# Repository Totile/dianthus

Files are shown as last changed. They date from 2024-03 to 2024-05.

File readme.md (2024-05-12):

# Dianthus

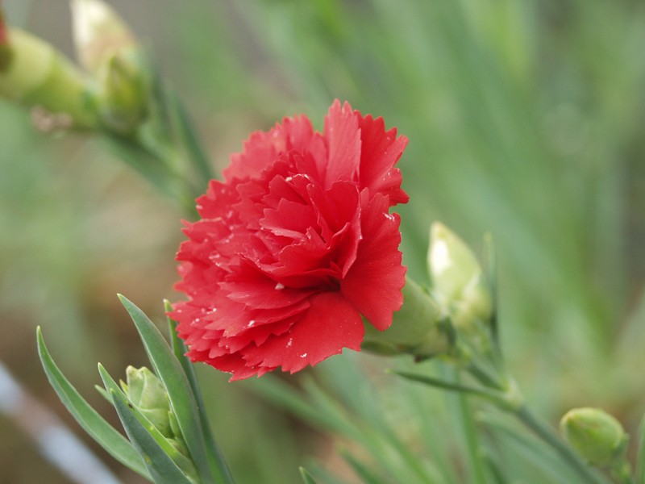
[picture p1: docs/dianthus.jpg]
Dianthus


*In the world of GUI, less mouse pointers, more fat fingers buttons.* 

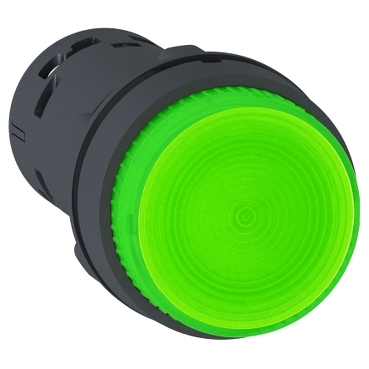
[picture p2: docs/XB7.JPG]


A button box to interface with web-based GUI, when you want to just push on buttons to do repetitive tasks. This replaces the need for the small buttons of a keyboard, or *worse*, a MOUSE.

* Hardware Supported: This box is based on the XB7 industrial button from Schneider electrics. And a promicro development board.
* Hardware Availability: 

## Installation guide

## Fabrication guide

All related documents can be found on the `livrables` folder (Procurement list, PCB production file, STL, ...)

### PCB Fabrication

### Schneider customisation button

### 3D printing files

The source files can be found on [Onshape project](https://cad.onshape.com/documents/cb52971ac28a8f36a2bdde5f/w/7d97d8c1100cd4f538ea172c/e/2ed6b61c8d6aeb3da16c9e53).

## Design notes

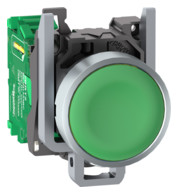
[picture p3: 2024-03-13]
docs/img/bigButton.jpg

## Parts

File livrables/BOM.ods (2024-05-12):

Nom | Quantité | Lien | Commentaire
Connecteur M12 vers câble | 1 | https://www.reichelt.de/fr/en/built-in-coupling-m12-5-pin-a-coded-ip67-black-lut-1220-05-100-p347082.html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
Alimentation 24V | 1 | https://www.automation24.fr/bloc-dalimentation-electrique-ifm-electronic-e80120
Câble Micro USB to USB-A | 1 | https://www.reichelt.de/fr/en/usb-a-connector-to-usb-micro-b-connector-green-2-m-shvp-bs1450015-p241114.html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
Connecteur USB A vers USB B | 1 | https://fr.rs-online.com/web/p/connecteurs-usb/8621573
Câble USB-B vers A | 1 | Voir ./fab
PCB | 1
Boîte | 1
Câble JST SH free on one side | 1 | https://www.mouser.de/ProductDetail/SparkFun/PRT-14426?qs=wd5RIQLrsJiogglVGK6o1w%3D%3D&vip=1&gad_source=1 | https://www.reichelt.de/fr/en/arduino-grove-universal-cable-4-pin-30cm-buckled-5er-bag--grv-cable4pin30f-p191162.html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
Bouton poussoir rétroéclairé | 5 | https://www.rexel.fr/frx/Cat%C3%A9gorie/Produits-Industriels/Commande-et-signalisation/Bouton-poussoir-et-tournant/Harmony-bouton-poussoir-lumineux---D%3D22--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 | XB7NW33B1
Boite ABPH 1600/1680 x 100 | 1 |  | https://www.bopla.de/fr/technique-de-boitiers/bos-ecoline/profiles-de-boitier-divises-horizontalement-2
Support mural pour ABPH | 1 | https://www.bopla.de/fr/technique-de-boitiers/alubos/accessoires-6
Fixation VESA | 1 | https://www.bopla.de/fr/technique-de-boitiers/presse-etoupes-accessoires-universels/clips-et-supports

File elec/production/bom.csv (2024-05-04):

Designator | Footprint | Quantity | Value | LCSC Part #
C1 | 0402 | 1 | 0.1uF
C2 | 1206 | 1 | 10uF
J1 | DB301V-3.5-2P-GN-S | 1 | Screw terminal
J10, J11, J12, J2, J3, J4, J5, J6, J7, J8, J9 | JST_SH_BM04B-SRSS-TB_1x04-1MP_P1.00mm_Vertical | 11 | BM04B-SRSS-TB
MCU1 | ProMicro | 1 | ATMEGA32UA_PROMICRO
Q1, Q10, Q2, Q3, Q4, Q5, Q6, Q7, Q8, Q9 | SOT-23 | 10 | 2N7002
R1, R11, R13, R15, R17, R19, R2, R21, R23, R25, R27, R3, R4, R5, R6, R9 | 0805 | 16 | 10k
R10, R12, R14, R16, R18, R20, R22, R24, R26, R28 | 0805 | 10 | 1k
R7, R8 | 0805 | 2 | 4.7k
SW1 | YTS-C015-X | 1 | YTSA010
TP1, TP2, TP3, TP4, TP5 | TestPoint_THTPad_D3.0mm_Drill1.5mm | 5 | TestPoint_Probe
U1 | DIP-28_W7.62mm | 1 | MCP23017_SP

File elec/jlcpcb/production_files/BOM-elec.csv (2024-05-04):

Comment | Designator | Footprint | LCSC
10uF | C2 | C_1206_3216Metric | C13585
BM04B-SRSS-TB | J10,J11,J12,J2,J3,J4,J5,J6,J7,J8,J9 | JST_SH_BM04B-SRSS-TB_1x04-1MP_P1.00mm_Vertical | C160390
10k | R1,R11,R13,R15,R17,R19,R2,R21,R23,R25,R27,R3,R4,R5,R6,R9 | R_0805_2012Metric | C17414
1k | R10,R12,R14,R16,R18,R20,R22,R24,R26,R28 | R_0805_2012Metric | C17513
4.7k | R7,R8 | R_0805_2012Metric | C17675
YTSA010 | SW1 | YTS-C015-X | C2910844
0.1uF | C1 | C_0402_1005Metric | C307331
Screw terminal | J1 | DB301V-3.5-2P-GN-S | C695629
2N7002 | Q1,Q10,Q2,Q3,Q4,Q5,Q6,Q7,Q8,Q9 | SOT-23 | C8545
MCP23017_SP | U1 | DIP-28_W7.62mm
TestPoint_Probe | TP3 | TestPoint_THTPad_D3.0mm_Drill1.5mm
TestPoint_Probe | TP1 | TestPoint_THTPad_D3.0mm_Drill1.5mm
TestPoint_Probe | TP5 | TestPoint_THTPad_D3.0mm_Drill1.5mm
TestPoint_Probe | TP2 | TestPoint_THTPad_D3.0mm_Drill1.5mm
ATMEGA32UA_PROMICRO | MCU1 | ProMicro
TestPoint_Probe | TP4 | TestPoint_THTPad_D3.0mm_Drill1.5mm

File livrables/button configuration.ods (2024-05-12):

Description | Modular Product ID | Customisation code | Configuration file | Customisation code with bevel | Ordering process
UD / BD Blanc | ZB4BZ102 / ZBVB1 / ZB4BW313 | ZB4-24054AEDC | harmonyxb4-0506-2103.se | ZB4-2405328OC | Complete product / Illuminated Push button / Chromium plated / Round / Built-in flush / flush / Spring return / White / Yes / NO / 24V / AC/DC / With plain lens / Screw-clamp terminal / Basic sub assemblies / mounting 22.5 mm
Mesurer orange | ZB4BZ102 / ZBVB1 / ZB4BW353 | ZB4-24055GUYV | harmonyxb4-0506-2102.se | XB4-24054A48Y
Plat vert | ZB4BZ102 / ZBVB1 / ZB4BW333 | ZB4-24054AEDC | harmonyxb4-0506-2109.se | XB4-24054A4MR
Courbe rouge | ZB4BZ102 / ZBVB1 / ZB4BW343 | ZB4-24055GV77 | harmonyxb4-0506-2113.se | XB4-24054A4Y4 | 703 | Trend / 5847 | Tilde operator
Valider blanc | ZB4BZ102 / ZBVB1 / ZB4BW313 | ZB4-24055GVDY | harmonyxb4-0506-2133.se | ZB4-24054A6GX | 422 | Affirmative / selection / 6334A
Enregistrer bleu | ZB4BZ102 / ZBVB1 / ZB4BW363 | ZB4-24055GVQZ | harmonyxb4-0506-2137.se | XB4-24054A6QL

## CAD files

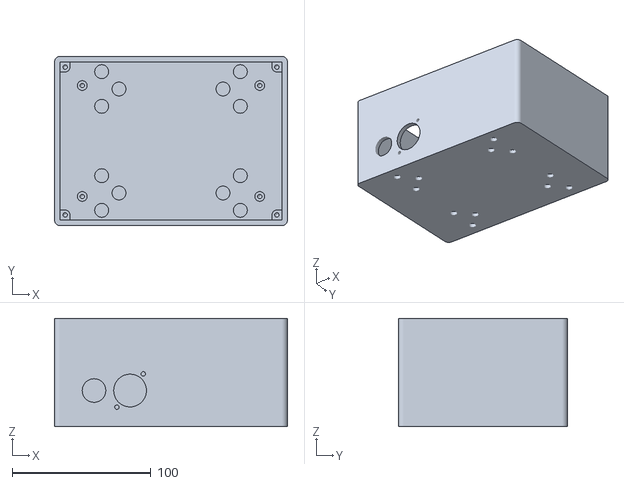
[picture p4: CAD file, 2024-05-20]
livrables/enclosure/box.stl
168.0 x 122.0 x 78.0

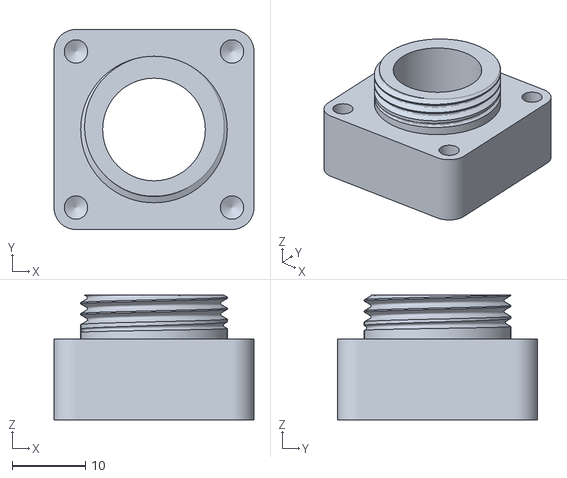
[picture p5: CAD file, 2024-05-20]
livrables/enclosure/rotary encoder housing.stl
27.3 x 27.3 x 17.0

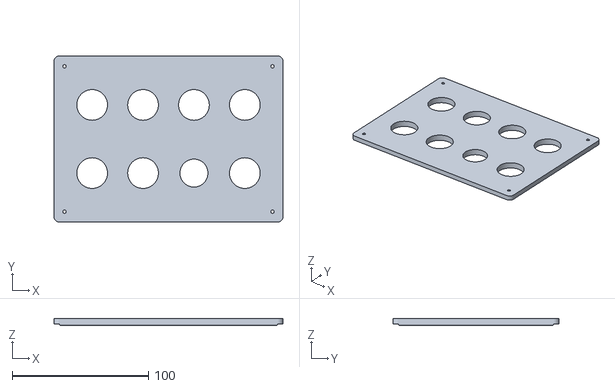
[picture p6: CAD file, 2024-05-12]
livrables/enclosure/cap 8 holes.stl
168.0 x 122.0 x 5.00

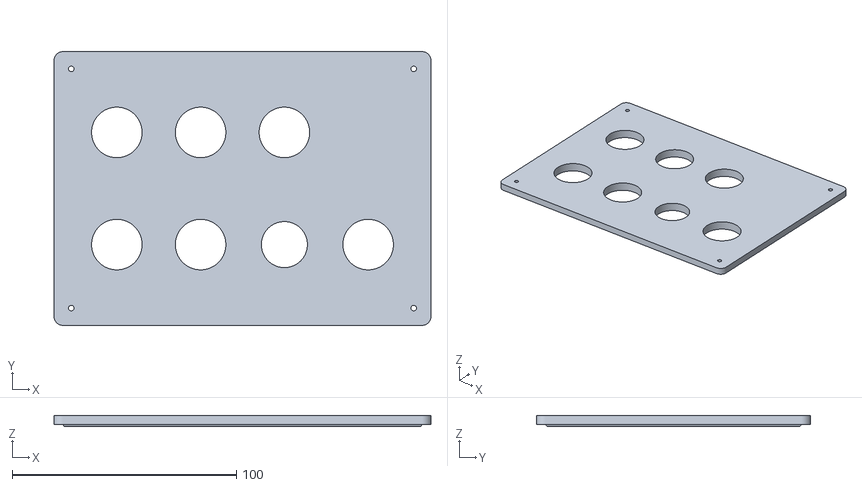
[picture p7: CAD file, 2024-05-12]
livrables/enclosure/cap 7 holes.stl
168.0 x 122.0 x 5.00

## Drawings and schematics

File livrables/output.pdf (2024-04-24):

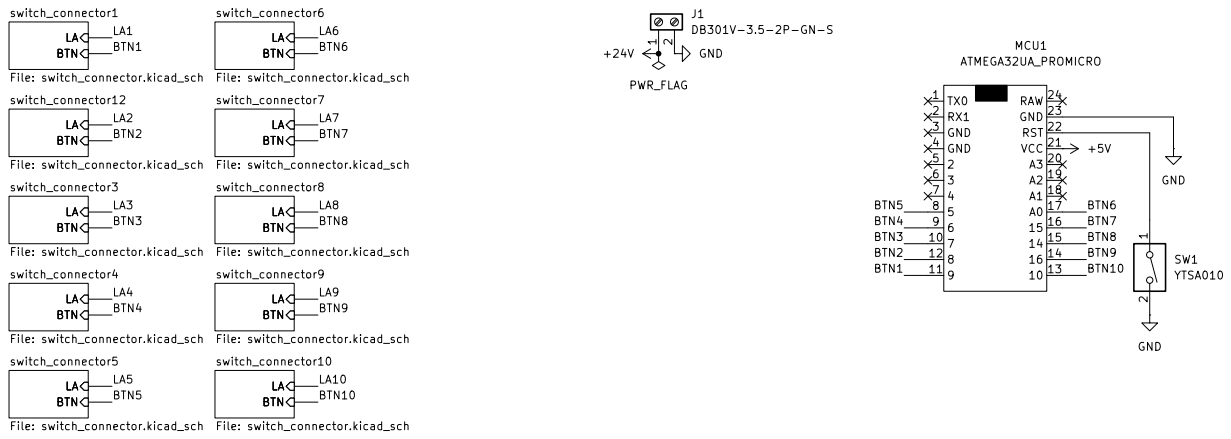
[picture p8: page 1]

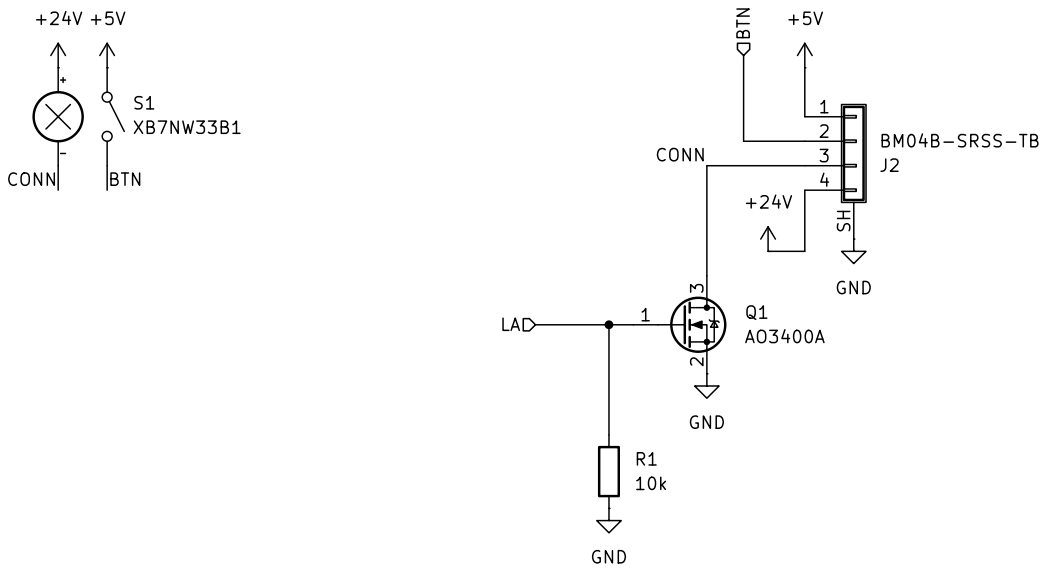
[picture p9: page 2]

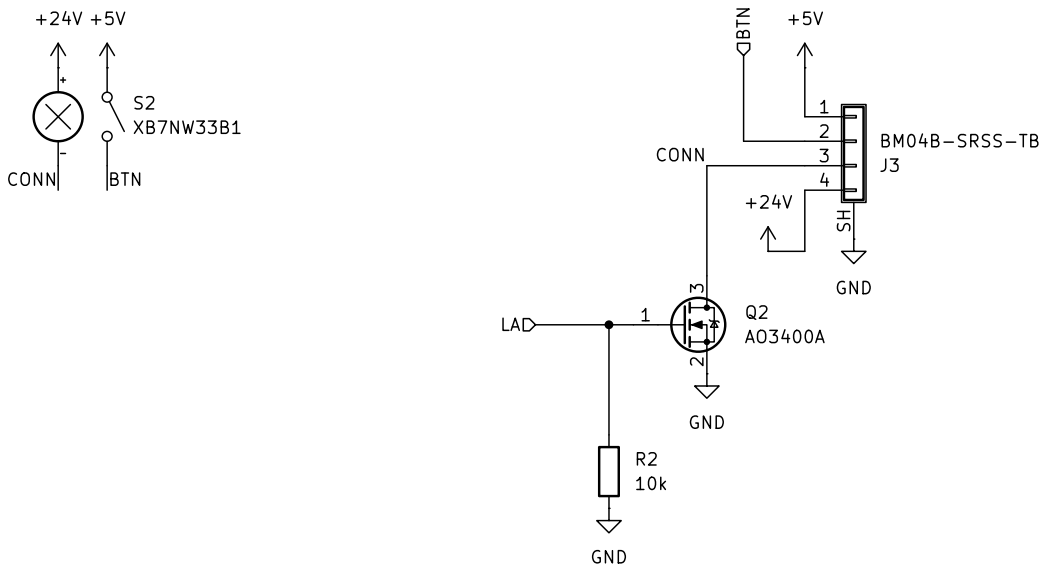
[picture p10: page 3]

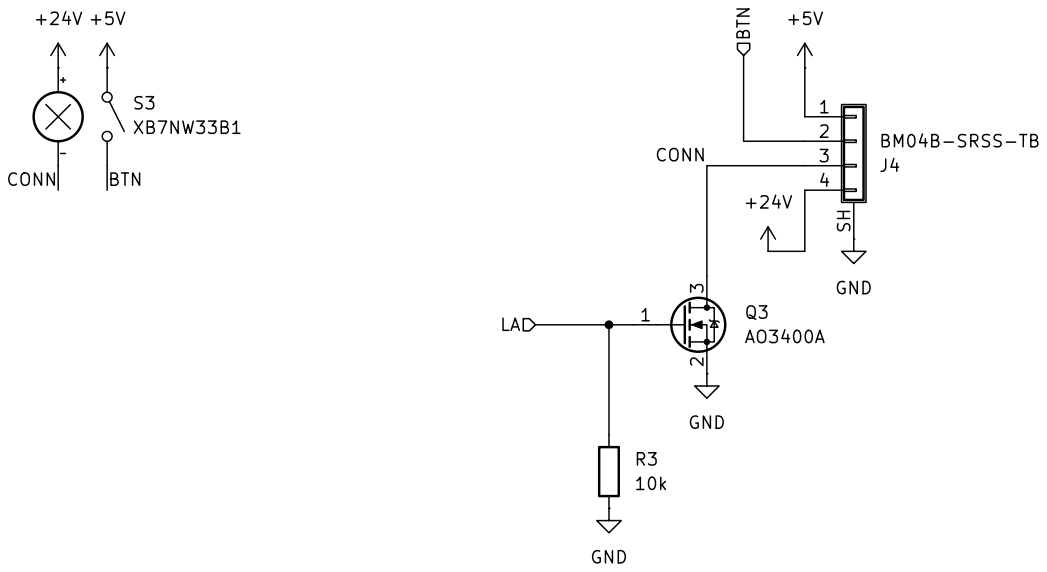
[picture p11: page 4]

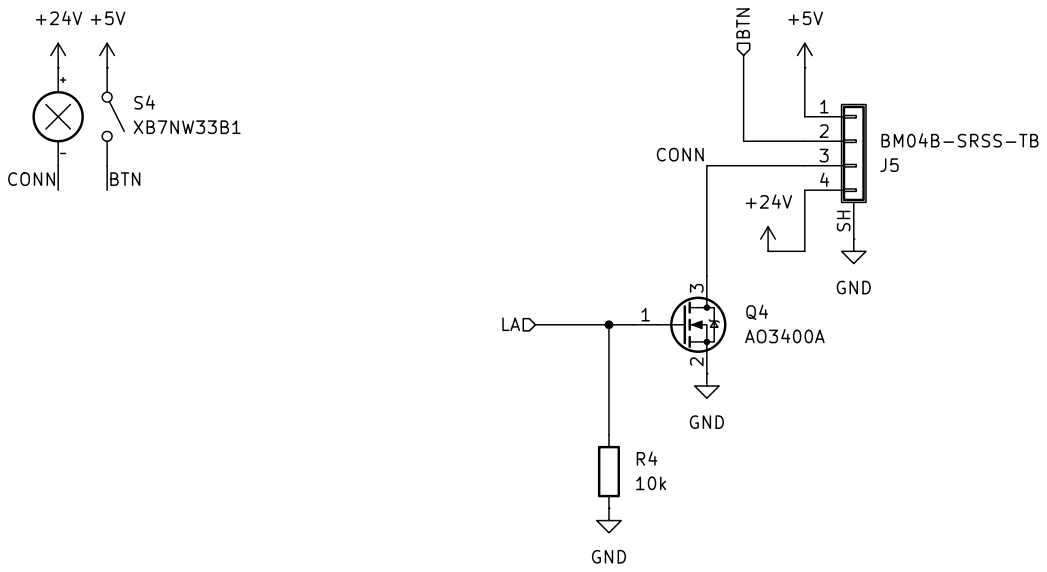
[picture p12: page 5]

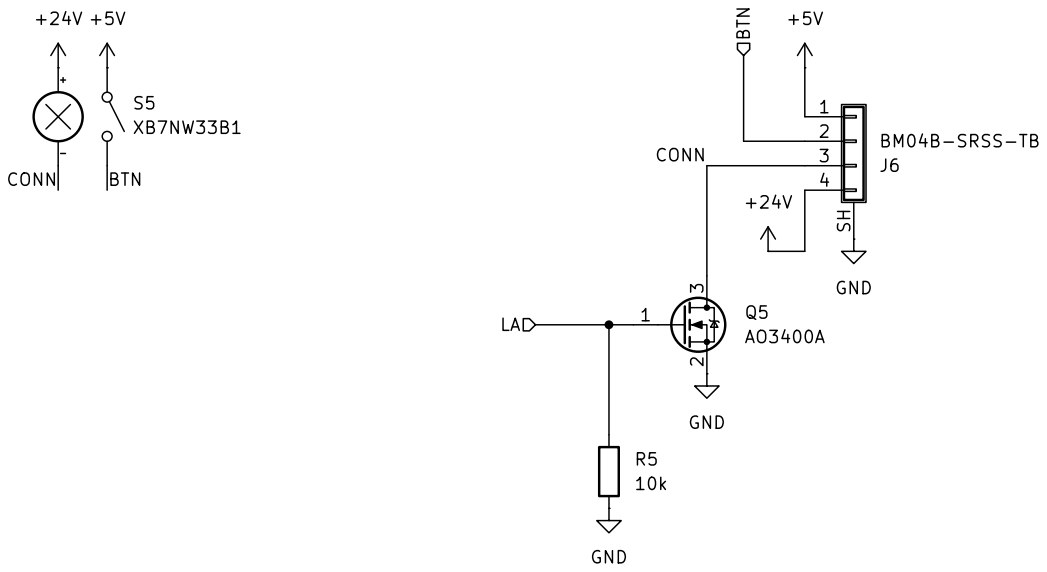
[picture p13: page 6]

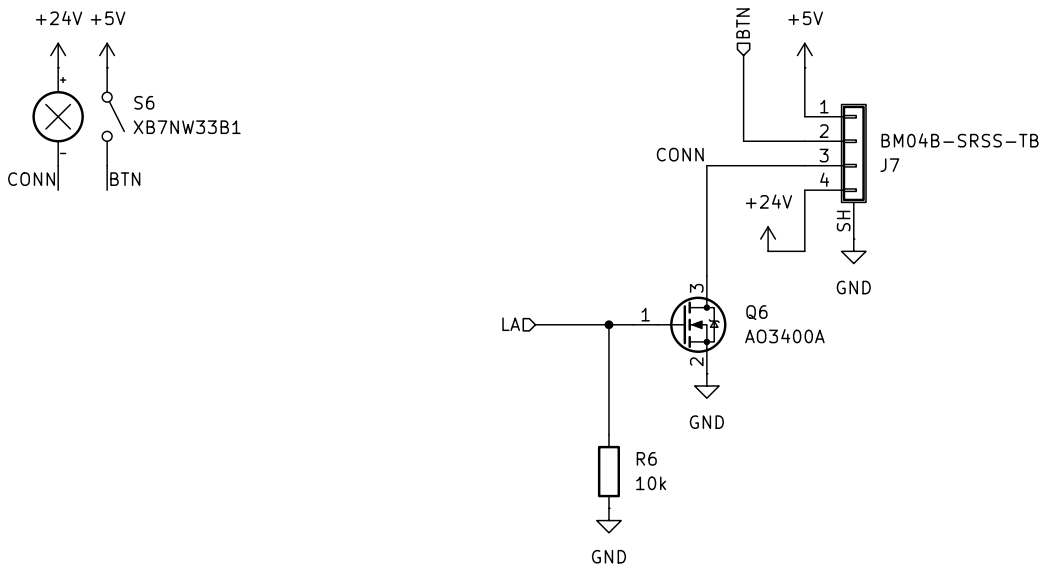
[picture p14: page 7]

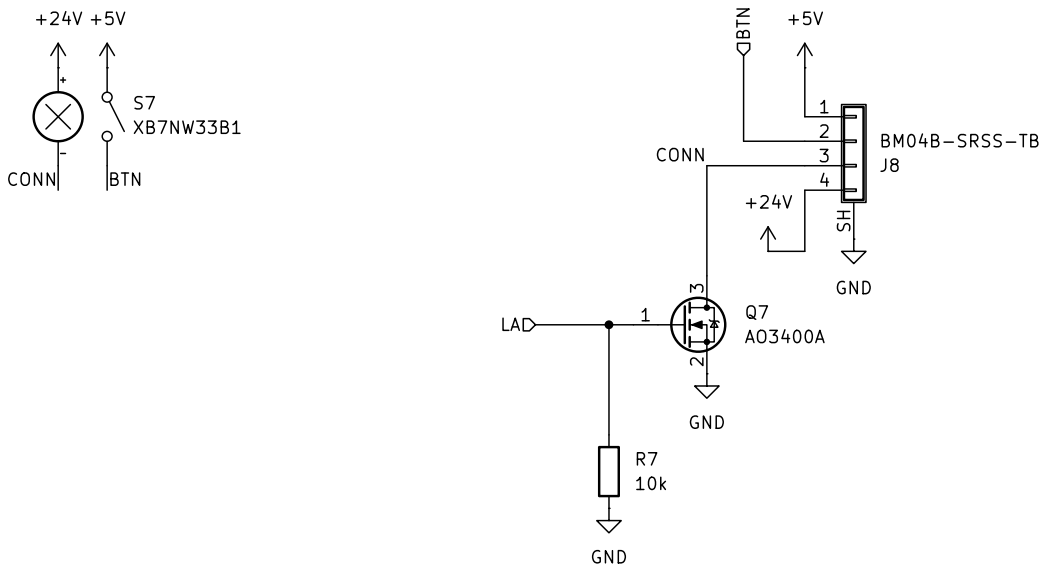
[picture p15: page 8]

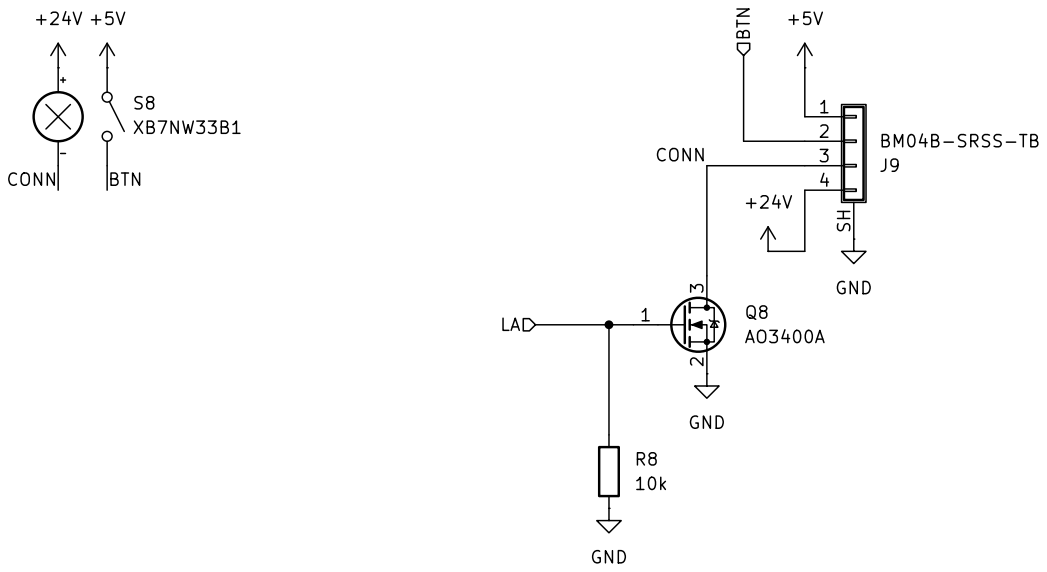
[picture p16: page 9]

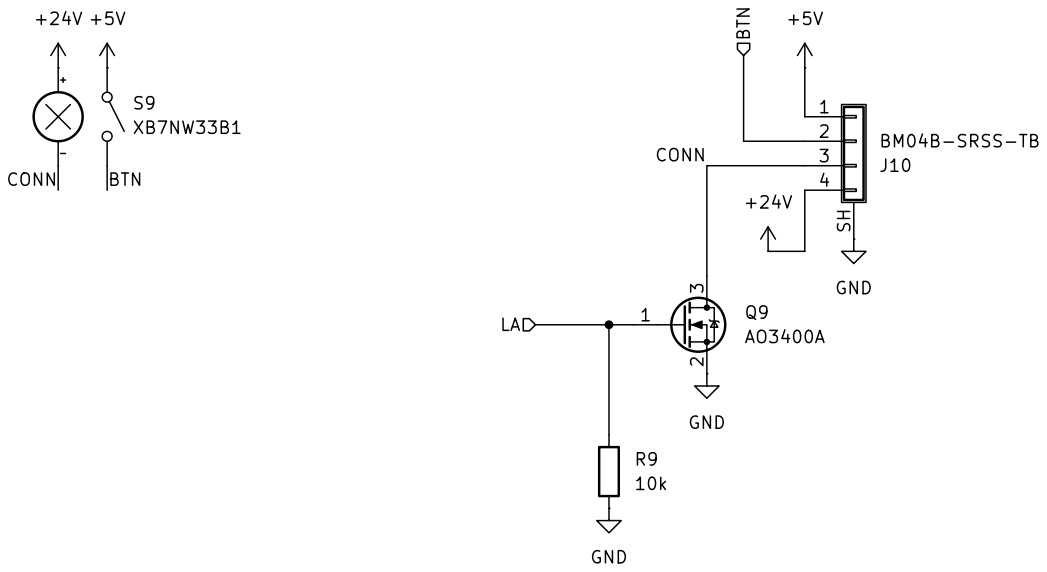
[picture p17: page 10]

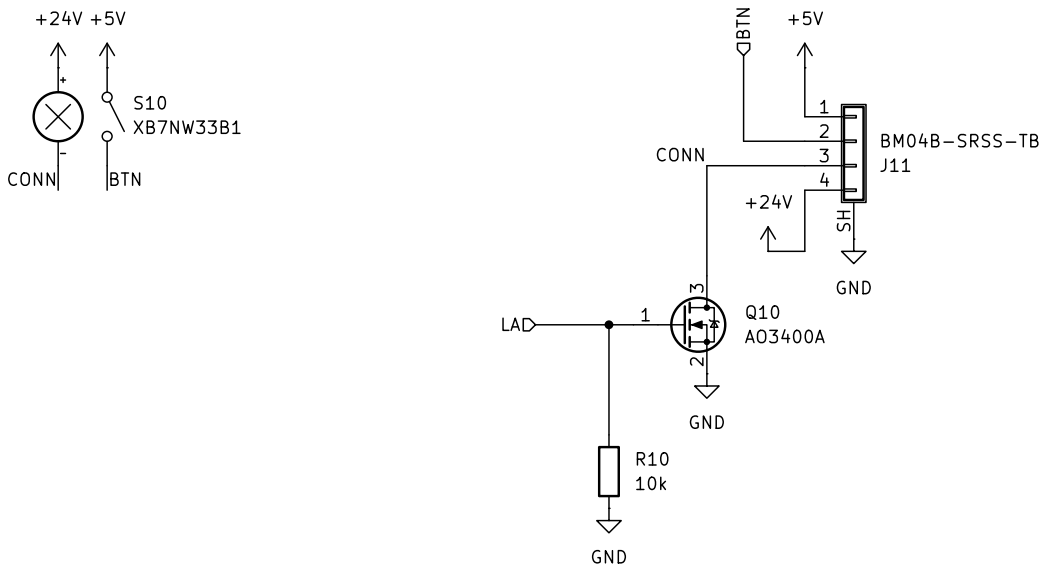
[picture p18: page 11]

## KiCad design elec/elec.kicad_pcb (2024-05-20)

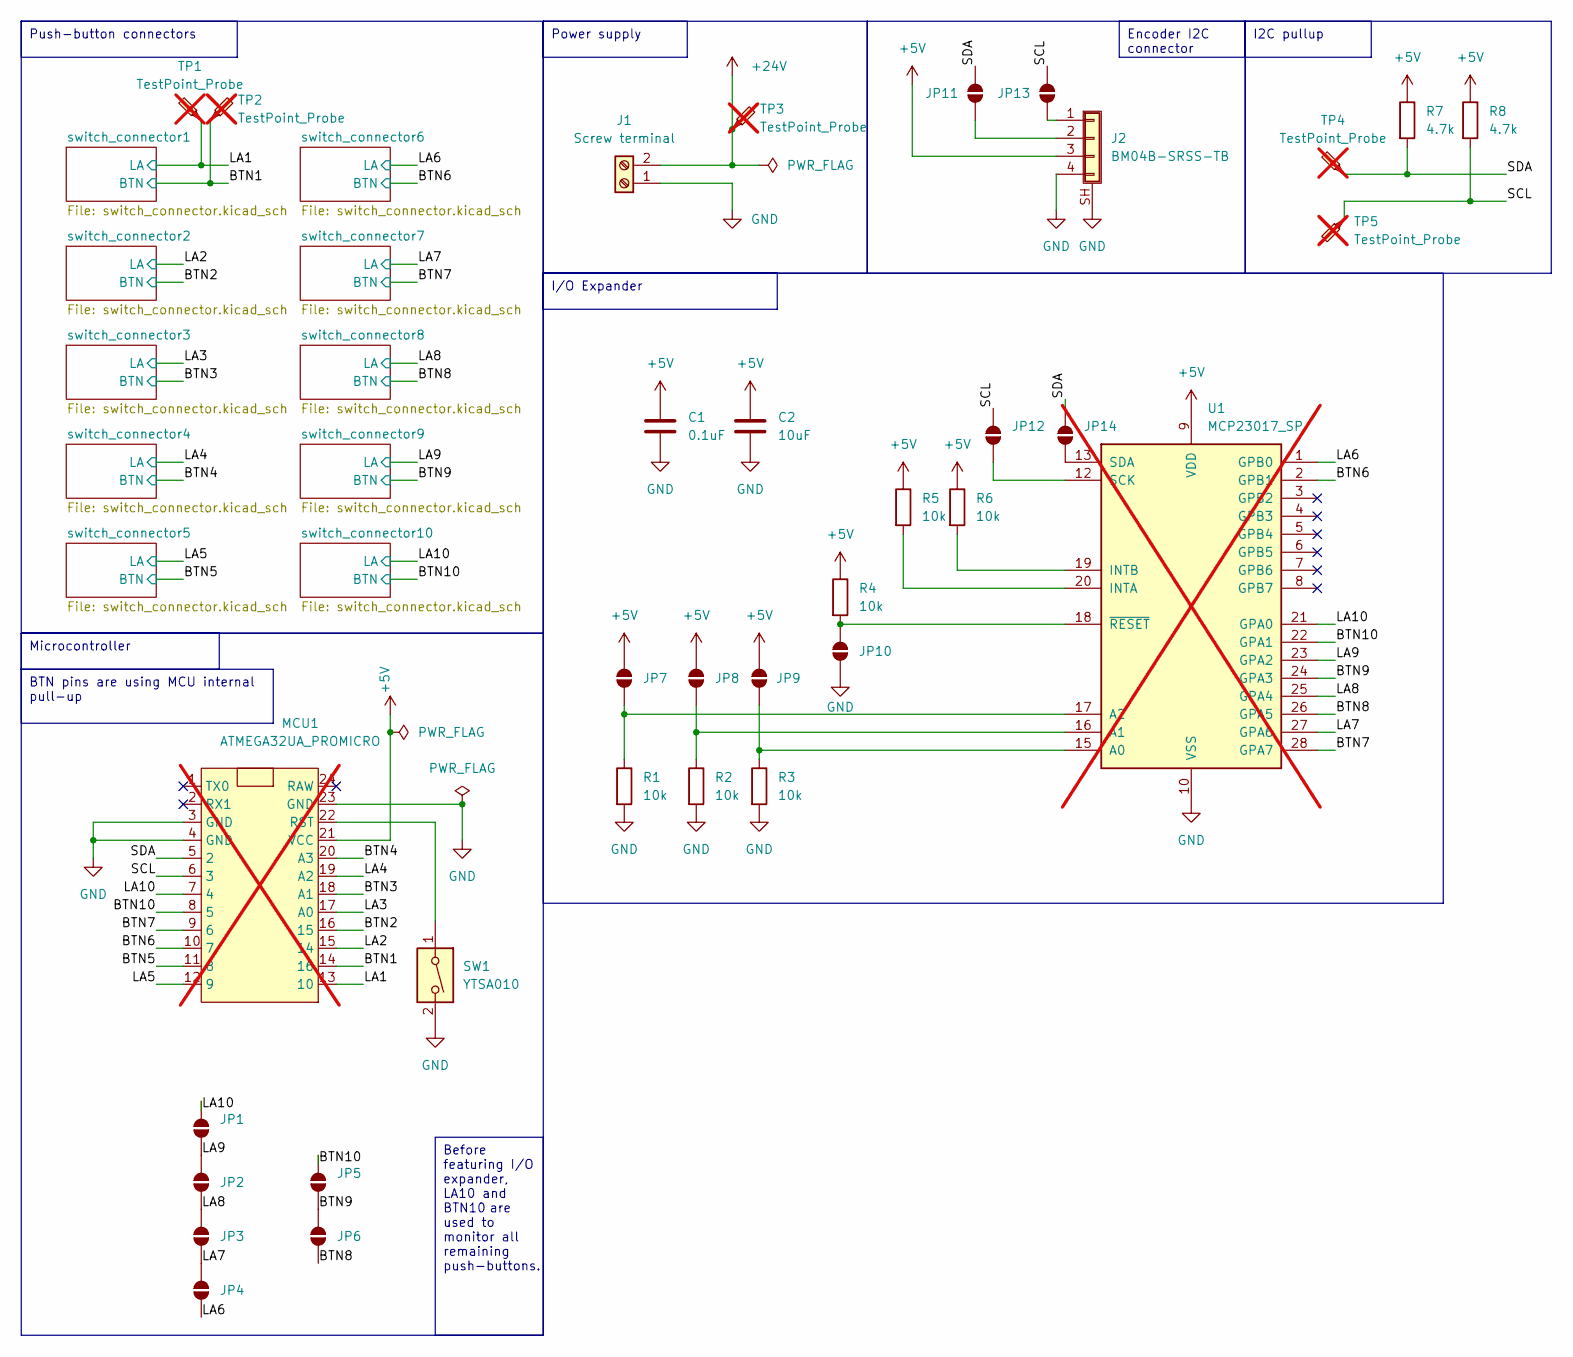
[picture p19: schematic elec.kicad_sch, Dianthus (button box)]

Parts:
C1: 0.1uF; C_0402_1005Metric; MPN C307331
C2: 10uF; C_1206_3216Metric; MPN C13585
J1: Screw terminal; DB301V-3.5-2P-GN-S; MPN C695629
J2: BM04B-SRSS-TB; JST_SH_BM04B-SRSS-TB_1x04-1MP_P1.00mm_Vertical; MPN C160390
JP1, JP2, JP3, JP4, JP5, JP6, JP7, JP8, JP9, JP10, JP11, JP12, JP13, JP14: SolderJumper_2_Open; SolderJumper-2_P1.3mm_Open_Pad1.0x1.5mm
MCU1: ATMEGA32UA_PROMICRO; ProMicro; not fitted
R1, R2, R3, R4, R5: 10k; R_0805_2012Metric; MPN C17414
R6: 10k; R_0805_2012Metric
R7, R8: 4.7k; R_0805_2012Metric; MPN C17675
SW1: YTSA010; YTS-C015-X; MPN C2910844
TP1, TP2, TP3, TP4, TP5: TestPoint_Probe; TestPoint_THTPad_D3.0mm_Drill1.5mm; not fitted
U1: MCP23017_SP; DIP-28_W7.62mm; not fitted

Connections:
+5V: C1.1, C2.1, J2.3, JP7.1 (A), JP8.1 (A), JP9.1 (A), MCU1.21 (VCC), R4.1, R5.1, R6.1, R7.1, R8.1, U1.9 (VDD)
+24V: J1.2, TP3.1; also elsewhere on the board
/BTN1: MCU1.14 (16), TP2.1; also elsewhere on the board
/BTN2: MCU1.16 (15); also elsewhere on the board
/BTN3: MCU1.18 (A1); also elsewhere on the board
/BTN4: MCU1.20 (A3); also elsewhere on the board
/BTN5: MCU1.11 (8); also elsewhere on the board
/BTN6: MCU1.10 (7), U1.2 (GPB1); also elsewhere on the board
/BTN7: MCU1.9 (6), U1.28 (GPA7); also elsewhere on the board
/BTN8: JP6.2 (B), U1.26 (GPA5); also elsewhere on the board
/BTN9: JP5.1 (A), JP6.1 (A), U1.24 (GPA3); also elsewhere on the board
/BTN10: JP5.2 (B), MCU1.8 (5), U1.22 (GPA1); also elsewhere on the board
/LA1: MCU1.13 (10), TP1.1; also elsewhere on the board
/LA2: MCU1.15 (14); also elsewhere on the board
/LA3: MCU1.17 (A0); also elsewhere on the board
/LA4: MCU1.19 (A2); also elsewhere on the board
/LA5: MCU1.12 (9); also elsewhere on the board
/LA6: JP4.1 (A), U1.1 (GPB0); also elsewhere on the board
/LA7: JP3.1 (A), JP4.2 (B), U1.27 (GPA6); also elsewhere on the board
/LA8: JP2.2 (B), JP3.2 (B), U1.25 (GPA4); also elsewhere on the board
/LA9: JP1.1 (A), JP2.1 (A), U1.23 (GPA2); also elsewhere on the board
/LA10: JP1.2 (B), MCU1.7 (4), U1.21 (GPA0); also elsewhere on the board
/SCL: JP12.2 (B), JP13.2 (B), MCU1.6 (3), R8.2, TP5.1
/SDA: JP11.2 (B), JP14.1 (A), MCU1.5 (2), R7.2, TP4.1
GND: C1.2, C2.2, J1.1, J2.4, J2.SH (Shield), JP10.1 (A), MCU1.3 (GND), MCU1.4 (GND), MCU1.23 (GND), R1.2, R2.2, R3.2, SW1.2, U1.10 (VSS); also elsewhere on the board
unnamed: J2.1, JP13.1 (A)
unnamed: J2.2, JP11.1 (A)
unnamed: JP7.2 (B), R1.1, U1.17 (A2)
unnamed: JP8.2 (B), R2.1, U1.16 (A1)
unnamed: JP9.2 (B), R3.1, U1.15 (A0)
unnamed: JP10.2 (B), R4.2, U1.18 (~RESET)
unnamed: JP12.1 (A), U1.12 (SCK)
unnamed: JP14.2 (B), U1.13 (SDA)
unnamed: MCU1.22 (RST), SW1.1
unnamed: R5.2, U1.20 (INTA)
unnamed: R6.2, U1.19 (INTB)

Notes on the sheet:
I2C pullup
Encoder I2C connector
BTN pins are using MCU internal pull-up
Push-button connectors
Before featuring I/O expander, LA10 and BTN10 are used to monitor all remaining push-buttons.
Power supply
I/O Expander
Microcontroller

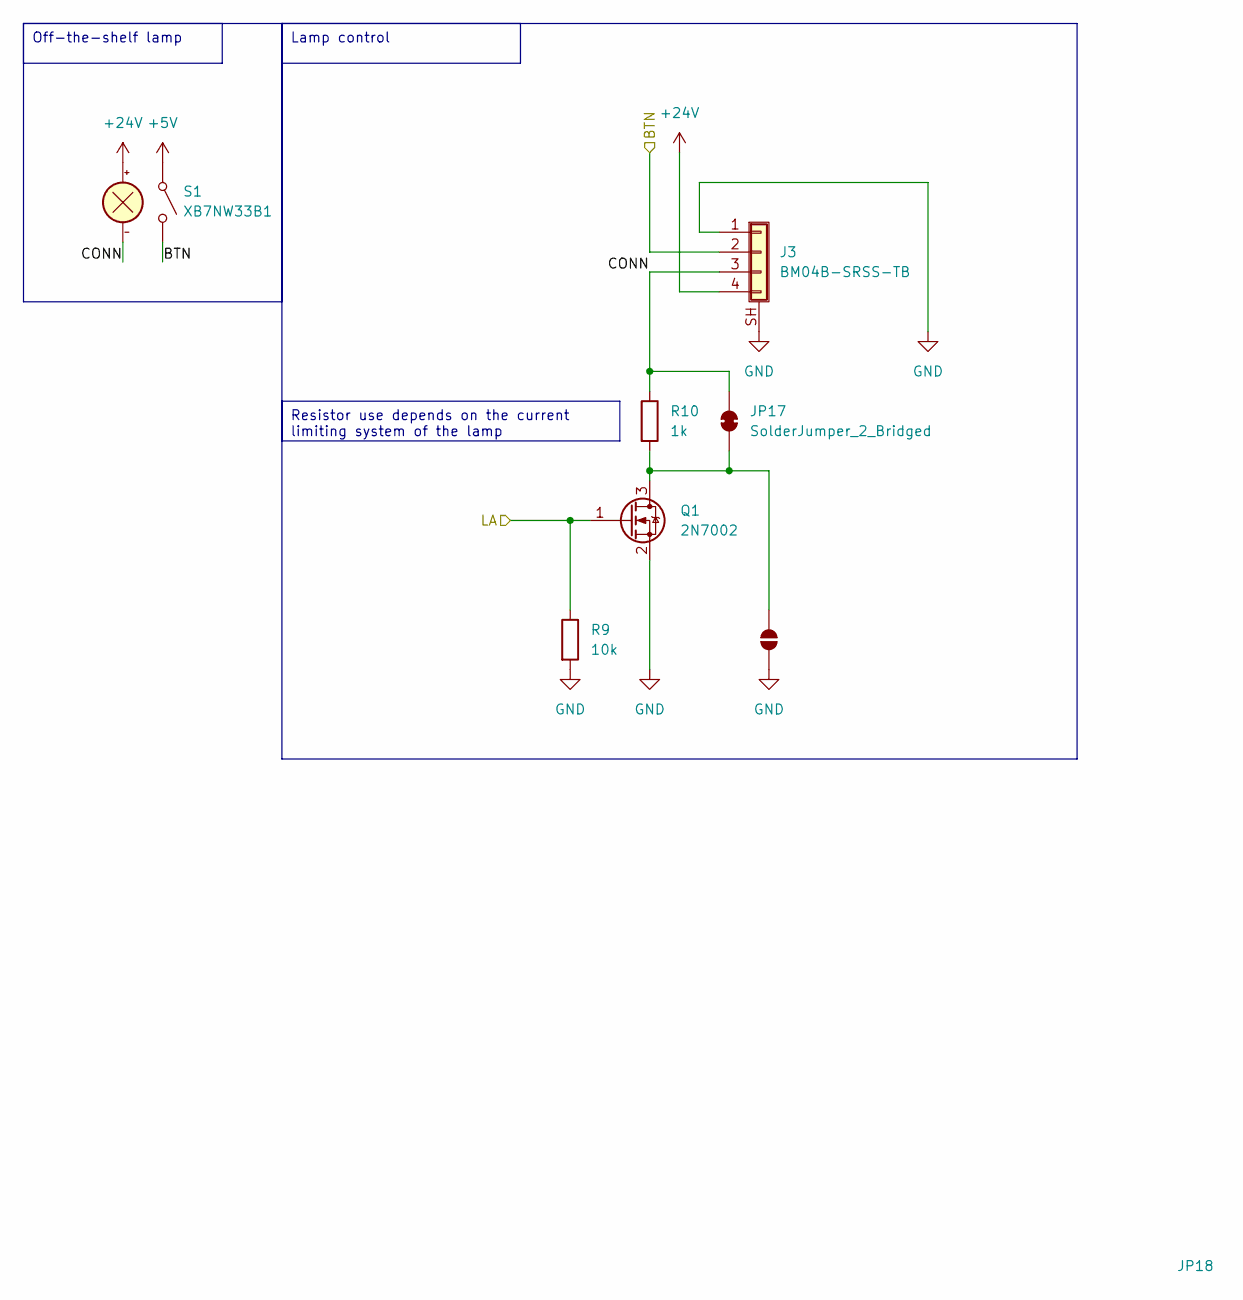
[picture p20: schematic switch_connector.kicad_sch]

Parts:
J3: BM04B-SRSS-TB; JST_SH_BM04B-SRSS-TB_1x04-1MP_P1.00mm_Vertical; MPN C160390
JP17: SolderJumper_2_Bridged; SolderJumper-2_P1.3mm_Bridged_Pad1.0x1.5mm
JP18: SolderJumper_2_Open; SolderJumper-2_P1.3mm_Open_Pad1.0x1.5mm
Q1: 2N7002; SOT-23; MPN C8545
R9: 10k; R_0805_2012Metric; MPN C17414
R10: 1k; R_0805_2012Metric; MPN C17513
S1: XB7NW33B1

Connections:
+24V: J3.4, S1.3 (x1(-)); also elsewhere on the board
/BTN1: J3.2; also elsewhere on the board
/LA1: Q1.1 (G), R9.1; also elsewhere on the board
GND: J3.1, J3.SH (Shield), JP18.2 (B), Q1.2 (S), R9.2; also elsewhere on the board

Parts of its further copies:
J4, J5, J6, J7, J8, J9, J10, J11, J12: BM04B-SRSS-TB; JST_SH_BM04B-SRSS-TB_1x04-1MP_P1.00mm_Vertical; MPN C160390
JP15, JP19, JP21, JP23, JP25, JP27, JP29, JP31, JP33: SolderJumper_2_Bridged; SolderJumper-2_P1.3mm_Bridged_Pad1.0x1.5mm
JP16, JP20, JP22, JP24, JP26, JP28, JP30, JP32, JP34: SolderJumper_2_Open; SolderJumper-2_P1.3mm_Open_Pad1.0x1.5mm
Q2, Q3, Q4, Q5, Q6, Q7, Q8, Q9, Q10: 2N7002; SOT-23; MPN C8545
R11, R13, R15, R17, R19, R21, R23, R25, R27: 10k; R_0805_2012Metric; MPN C17414
R12, R14, R16, R18, R20, R22, R24, R26, R28: 1k; R_0805_2012Metric; MPN C17513

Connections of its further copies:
+24V: J4.4, J5.4, J6.4, J7.4, J8.4, J9.4, J10.4, J11.4, J12.4; also elsewhere on the board
/BTN2: J4.2; also elsewhere on the board
/BTN3: J5.2; also elsewhere on the board
/BTN4: J6.2; also elsewhere on the board
/BTN5: J7.2; also elsewhere on the board
/BTN6: J8.2; also elsewhere on the board
/BTN7: J9.2; also elsewhere on the board
/BTN8: J10.2; also elsewhere on the board
/BTN9: J11.2; also elsewhere on the board
/BTN10: J12.2; also elsewhere on the board
/LA2: Q2.1 (G), R11.1; also elsewhere on the board
/LA3: Q3.1 (G), R13.1; also elsewhere on the board
/LA4: Q4.1 (G), R15.1; also elsewhere on the board
/LA5: Q5.1 (G), R17.1; also elsewhere on the board
/LA6: Q6.1 (G), R19.1; also elsewhere on the board
/LA7: Q7.1 (G), R21.1; also elsewhere on the board
/LA8: Q8.1 (G), R23.1; also elsewhere on the board
/LA9: Q9.1 (G), R25.1; also elsewhere on the board
/LA10: Q10.1 (G), R27.1; also elsewhere on the board
/switch_connector3/CONN: J5.3, JP19.2 (B), R14.1
/switch_connector4/CONN: J6.3, JP21.2 (B), R16.1
/switch_connector5/CONN: J7.3, JP23.2 (B), R18.1
/switch_connector6/CONN: J8.3, JP25.2 (B), R20.1
/switch_connector7/CONN: J9.3, JP27.2 (B), R22.1
/switch_connector8/CONN: J10.3, JP29.2 (B), R24.1
/switch_connector9/CONN: J11.3, JP31.2 (B), R26.1
/switch_connector10/CONN: J12.3, JP33.2 (B), R28.1
GND: J4.1, J4.SH (Shield), J5.1, J5.SH (Shield), J6.1, J6.SH (Shield), J7.1, J7.SH (Shield), J8.1, J8.SH (Shield), J9.1, J9.SH (Shield), J10.1, J10.SH (Shield), J11.1, J11.SH (Shield), J12.1, J12.SH (Shield), JP16.2 (B), JP20.2 (B), JP22.2 (B), JP24.2 (B), JP26.2 (B), JP28.2 (B), JP30.2 (B), JP32.2 (B), JP34.2 (B), Q2.2 (S), Q3.2 (S), Q4.2 (S), Q5.2 (S), Q6.2 (S), Q7.2 (S), Q8.2 (S), Q9.2 (S), Q10.2 (S), R11.2, R13.2, R15.2, R17.2, R19.2, R21.2, R23.2, R25.2, R27.2; also elsewhere on the board
unnamed: JP19.1 (A), JP20.1 (A), Q3.3 (D), R14.2
unnamed: JP21.1 (A), JP22.1 (A), Q4.3 (D), R16.2
unnamed: JP23.1 (A), JP24.1 (A), Q5.3 (D), R18.2
unnamed: JP25.1 (A), JP26.1 (A), Q6.3 (D), R20.2
unnamed: JP27.1 (A), JP28.1 (A), Q7.3 (D), R22.2
unnamed: JP29.1 (A), JP30.1 (A), Q8.3 (D), R24.2
unnamed: JP31.1 (A), JP32.1 (A), Q9.3 (D), R26.2
unnamed: JP33.1 (A), JP34.1 (A), Q10.3 (D), R28.2

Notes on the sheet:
Resistor use depends on the current limiting system of the lamp
Lamp control
Off-the-shelf lamp

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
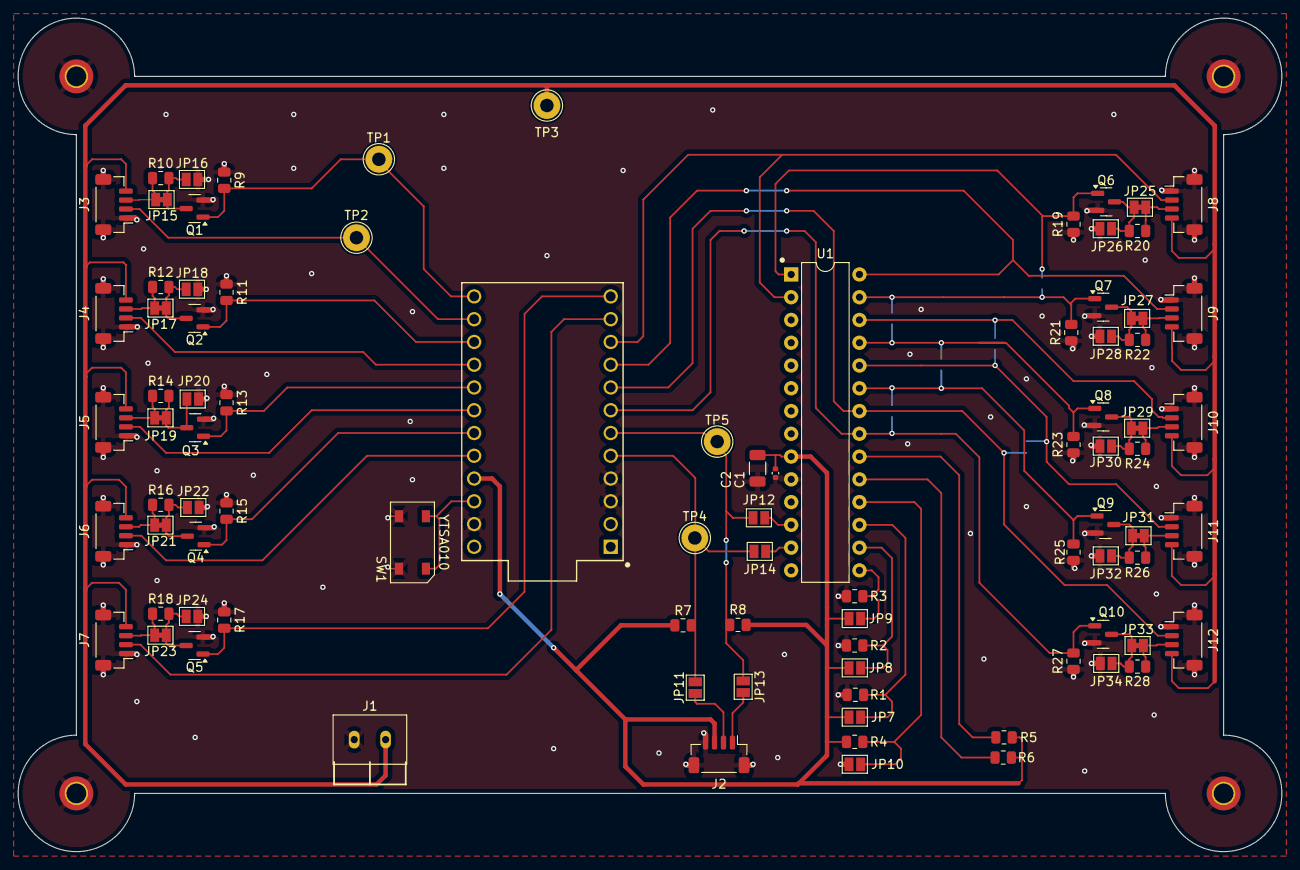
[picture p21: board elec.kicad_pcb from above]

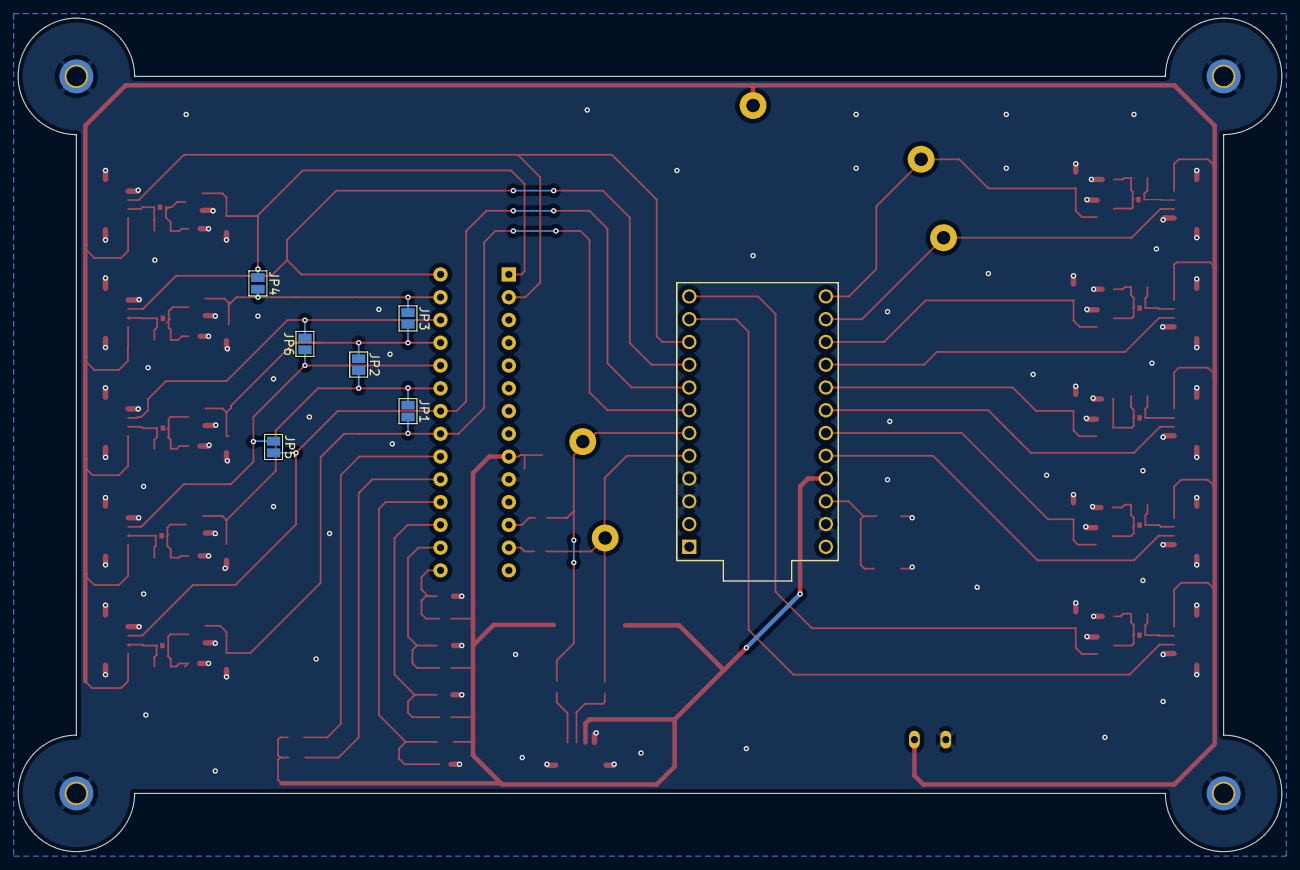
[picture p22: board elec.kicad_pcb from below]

Board: 2 copper layers, 141.0 x 93.0 mm, 94 parts (6 on the bottom side), 56 nets.

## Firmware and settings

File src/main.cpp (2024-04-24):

#include "Arduino.h"
#include "Joystick.h"
#include "debounce.h"

// Pinout definition
const int PIN_LED1 = 3;
const int PIN_BTN1 = 15;
const int PIN_LED2 = 4;
const int PIN_BTN2 = 14;
const int PIN_LED3 = 5;
const int PIN_BTN3 = 16;

// Joystick initialisation
// TODO try to set it as a Gamepad, not a joystick
Joystick_ Joystick;

void buttonHandler(uint8_t btnID, uint8_t btnSTate) {
    if (btnSTate == BTN_PRESSED) {
        Joystick.pressButton(btnID);
        Serial.print("Button ");
        Serial.print(btnID);
        Serial.println(" pressed");
        digitalWrite(PIN_LED1, 1);
    } else {
        Joystick.releaseButton(btnID);
        Serial.print("Button ");
        Serial.print(btnID);
        Serial.println(" released");
        digitalWrite(PIN_LED1, 0);
    }
}

static Button btn1(0, buttonHandler);
static Button btn2(1, buttonHandler);
static Button btn3(2, buttonHandler);

void setup() {
    pinMode(PIN_BTN1, INPUT_PULLUP);
    pinMode(PIN_BTN2, INPUT_PULLUP);
    pinMode(PIN_BTN3, INPUT_PULLUP);
    pinMode(PIN_LED1, OUTPUT);

    Serial.begin(9600);
    Joystick.begin();
}

static void pollButtons() {
    btn1.update(digitalRead(PIN_BTN1));
    btn2.update(digitalRead(PIN_BTN2));
    btn3.update(digitalRead(PIN_BTN3));
}

void loop() {
    pollButtons();
    delay(10);
}

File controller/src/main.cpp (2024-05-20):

#include "Arduino.h"
#include "Joystick.h"
#include "debounce.h"

// Pinout definition
constexpr int lampCount = 6;
constexpr int btnCount = 8;
const int lampPin[lampCount] = {10, 14, A0, A2, 9, 4};
const int btnPin[btnCount] = {16, 15, A1, A3, 8, 7, 6, 5};

// Joystick initialisation
// TODO try to set it as a Gamepad, not a joystick
Joystick_ Joystick;

void buttonHandler(uint8_t btnID, uint8_t btnSTate) {
    if (btnSTate == BTN_PRESSED) {
        Joystick.pressButton(btnID);
        Serial.print("Button ");
        Serial.print(btnID);
        Serial.println(" pressed");
        digitalWrite(lampPin[0], 1);
    } else {
        Joystick.releaseButton(btnID);
        Serial.print("Button ");
        Serial.print(btnID);
        Serial.println(" released");
        digitalWrite(lampPin[0], 0);
    }
}

Button btnArr[btnCount] = {};

void setup() {
    for (int i = 0; i < btnCount; i++) {
        pinMode(btnPin[i], INPUT_PULLUP);
    }
    for (int i = 0; i < lampCount; i++) {
        pinMode(lampPin[i], OUTPUT);
    }
    for (int i = 0; i < btnCount; i++) {
        const Button tempBtn(i, buttonHandler);
        btnArr[i] = tempBtn;
    }

    Serial.begin(9600);
    Joystick.begin();
}

static void pollButtons() {
    for (int i = 0; i < btnCount; i++) {
        btnArr[i].update(digitalRead(btnPin[i]));
    }
}

void loop() {
    pollButtons();
    delay(1);
}

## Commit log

2024-03-24 chores: keep track of further reading documents
2024-03-29 3 button test with debounce
2024-04-19 first version without MOSFET
    [elec.kicad_pcb, elec.kicad_sch, switch_connector.kicad_sch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]
2024-04-24 feat: adding modularity to PCB
    [elec.kicad_pcb, elec.kicad_sch, switch_connector.kicad_sch]
2024-04-24 feat: pretty serial print
2024-04-24 tracking deliverables
    [BOM.ods]
2024-05-01 v1 3D print PCB
    [elec.kicad_pcb, elec.kicad_sch, switch_connector.kicad_sch]
2024-05-04 PCB rev1, with production files
2024-05-04 doc: outline for fabrication guide
    [BOM-elec.csv, bom.csv, designators.csv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]
2024-05-12 stl preparation
    [BOM.ods, button configuration.ods, cap - mm 7 holes.stl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]
2024-05-12 temp files for kicad
2024-05-20 main - feat: updating delivrables
    [box.stl, cap 7 holes.stl, cap 8 holes.stl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]
2024-05-20 dev - feat: 8 buttons with code repetition
2024-05-20 dev - refac: pin and lamp mode in for loop
2024-05-20 #1 - refac: further refactor of button loop definition
